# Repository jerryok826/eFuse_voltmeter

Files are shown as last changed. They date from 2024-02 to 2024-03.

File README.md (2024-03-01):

# eFuse Voltmeter
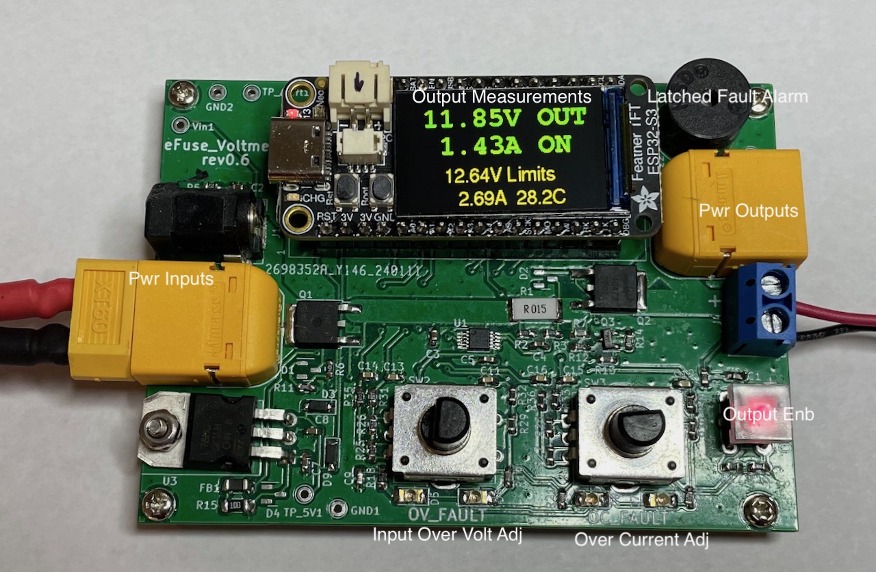
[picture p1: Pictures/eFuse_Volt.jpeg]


# eFuse Voltmeter in fault
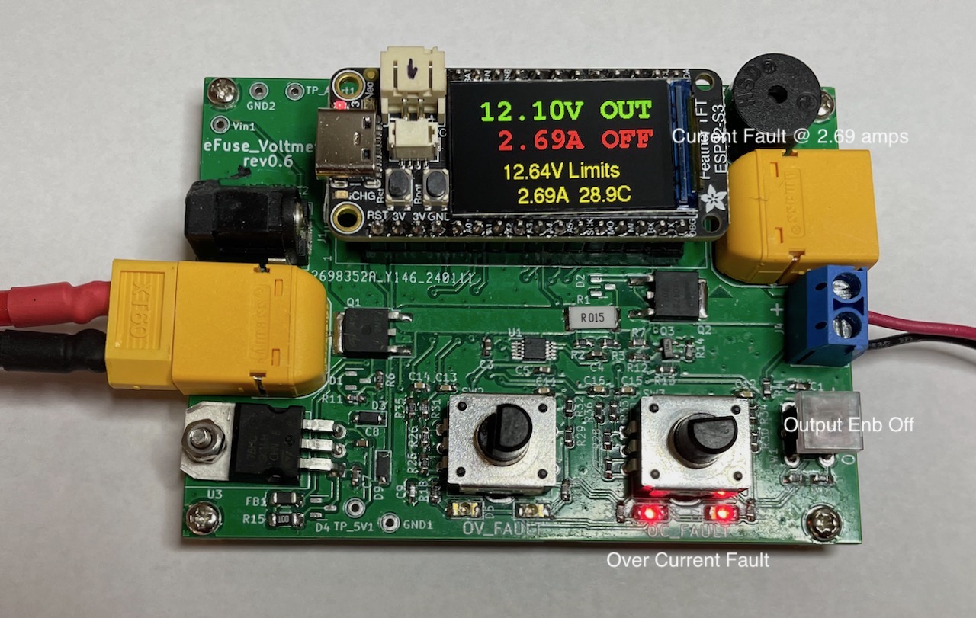
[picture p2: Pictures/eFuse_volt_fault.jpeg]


## Project Description
eFuse_Voltmeter is a protection circuit for down stream electronic devices. A eFuse. The initial reason for the device was to protect a Ham radio when adjustmenting power mosfet transistors biasing. The fets can hit thermal run-way and destroy traces.

It can be powered from any DC power source between 5 to 25 volts. Its been test up to 6 amps.  At 5 amps the two inline mostfets drop 150millvolts each and the sense resistor drops 81 millvolts. Except for the mosfets it should work at much higher currents. So two the mosfets should upgraded. 

Features:
1. Reverse power protection.
2. Adjustable input over voltage input protection
3. Adjustable over current protection.
4. Voltage and current monitoring.
5. Output power control.
6. Output power disconnected on fault.
7. Audio alarm on fault.

When an over voltage or an over current event happens the board will disable its output. The fault state is latched until the control buttons is pressed. Apond a fault an audio alarm is also actived and a fault LEDs is lite. The fault value is indicted by its red measurement value and the fault RED led is lite. A fault is cleared by pressing the adjusement button. The output button needs to be press again to reable the boards output.
 
### Project Status
The project is basically complete. Working on improvements.

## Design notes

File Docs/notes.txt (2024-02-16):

https://learn.adafruit.com/adafruit-hallowing/uf2-bootloader-details

https://github.com/adafruit/Adafruit_Learning_System_Guides/blob/main/Factory_Tests/Feather_ESP32S2_TFT_FactoryTest/Feather_ESP32S2_TFT_FactoryTest.ino

14:25:53.303 -> [0;32mI (611) esp_image: segment 0: paddr=00010020 vaddr=3c040020 size=0edf4h ( 60916) map[0m
14:25:53.303 -> [0;32mI (621) esp_image: segment 1: paddr=0001ee1c vaddr=3fc916f0 size=011fch (  4604) load[0m
14:25:53.303 -> [0;32mI (622) esp_image: segment 2: paddr=00020020 vaddr=42000020 size=33ec0h (212672) map[0m
14:25:53.336 -> [0;32mI (658) esp_image: segment 3: paddr=00053ee8 vaddr=3fc928ec size=02634h (  9780) load[0m
14:25:53.336 -> [0;32mI (661) esp_image: segment 4: paddr=00056524 vaddr=40374000 size=0d6e4h ( 55012) load[0m
14:25:53.370 -> [0;32mI (680) boot: Loaded app from partition at offset 0x10000[0m
14:25:53.370 -> [0;32mI (681) boot: Disabling RNG early entropy source...[0m
14:25:53.370 -> E (699) esp_core_dump_flash: No core dump partition found!
14:25:53.370 -> E (699) esp_core_dump_flash: No core dump partition found!

// reg at page 21
10:32:37.497 -> INA228 reg[00] 0x0000
10:32:37.497 -> INA228 reg[01] 0xFB68
10:32:37.497 -> INA228 reg[02] 0x1000
10:32:37.497 -> INA228 reg[03] 0x0000
10:32:37.497 -> INA228 reg[04] 0x00D2
10:32:37.497 -> INA228 reg[05] 0x0DCB
10:32:37.497 -> INA228 reg[06] 0x0ADE
10:32:37.530 -> INA228 reg[07] 0x00D2
10:32:37.530 -> INA228 reg[08] 0x002D
10:32:37.530 -> INA228 reg[09] 0x0000
10:32:37.530 -> INA228 reg[0A] 0x0000
10:32:37.530 -> INA228 reg[0B] 0x4003 // DIAG_ALRT pg 26
10:32:37.530 -> INA228 reg[0C] 0x7FFF
10:32:37.530 -> INA228 reg[0D] 0x8000
10:32:37.530 -> INA228 reg[0E] 0x7FFF
10:32:37.530 -> INA228 reg[0F] 0x0000
10:32:37.530 -> INA228 reg[10] 0x7FFF
10:32:37.530 -> INA228 reg[11] 0xFFFF
10:32:37.530 -> INA228 reg[3E] 0x5449
10:32:37.530 -> INA228 reg[3F] 0x2281

10:32:37.530 -> Averaging counts: 16
10:32:37.530 -> Voltage conversion time: 150 uS
10:32:37.530 -> Current conversion time: 280 uS

Address Acronym
Register NameRegister Size (bits)
Section
0hCONFIGConfiguration16Go
1hADC_CONFIGADC Configuration16Go
2hSHUNT_CALShunt Calibration16Go
3hSHUNT_TEMPCOShunt Temperature Coefficient16Go
4hVSHUNTShunt Voltage Measurement24Go
5hVBUSBus Voltage Measurement24Go
6hDIETEMPTemperature Measurement16Go
7hCURRENTCurrent Result24Go
8hPOWERPower Result24Go
9hENERGYEnergy Result40Go
AhCHARGECharge Result40Go
BhDIAG_ALRTDiagnostic Flags and Alert16Go
ChSOVLShunt Overvoltage Threshold16Go
DhSUVLShunt Undervoltage Threshold16Go
EhBOVLBus Overvoltage Threshold16Go
FhBUVLBus Undervoltage Threshold16Go
10hTEMP_LIMITTemperature Over-Limit
Threshold16Go
11hPWR_LIMITPower Over-Limit Threshold16Go
3EhMANUFACTURER_IDManufacturer ID16Go
3FhDEVICE_IDDevice ID16Go

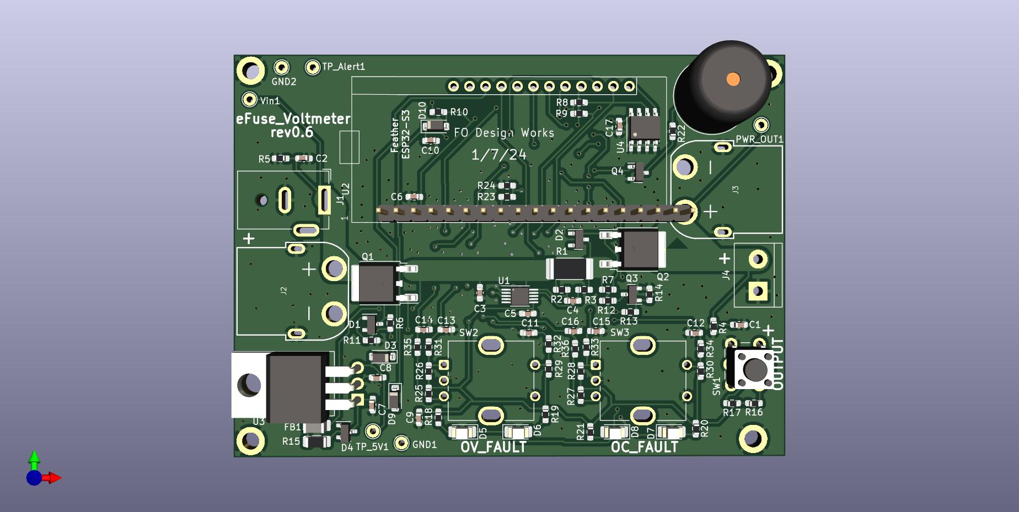
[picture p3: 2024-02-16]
Hardware/eFuse_voltmeter_r6.jpg

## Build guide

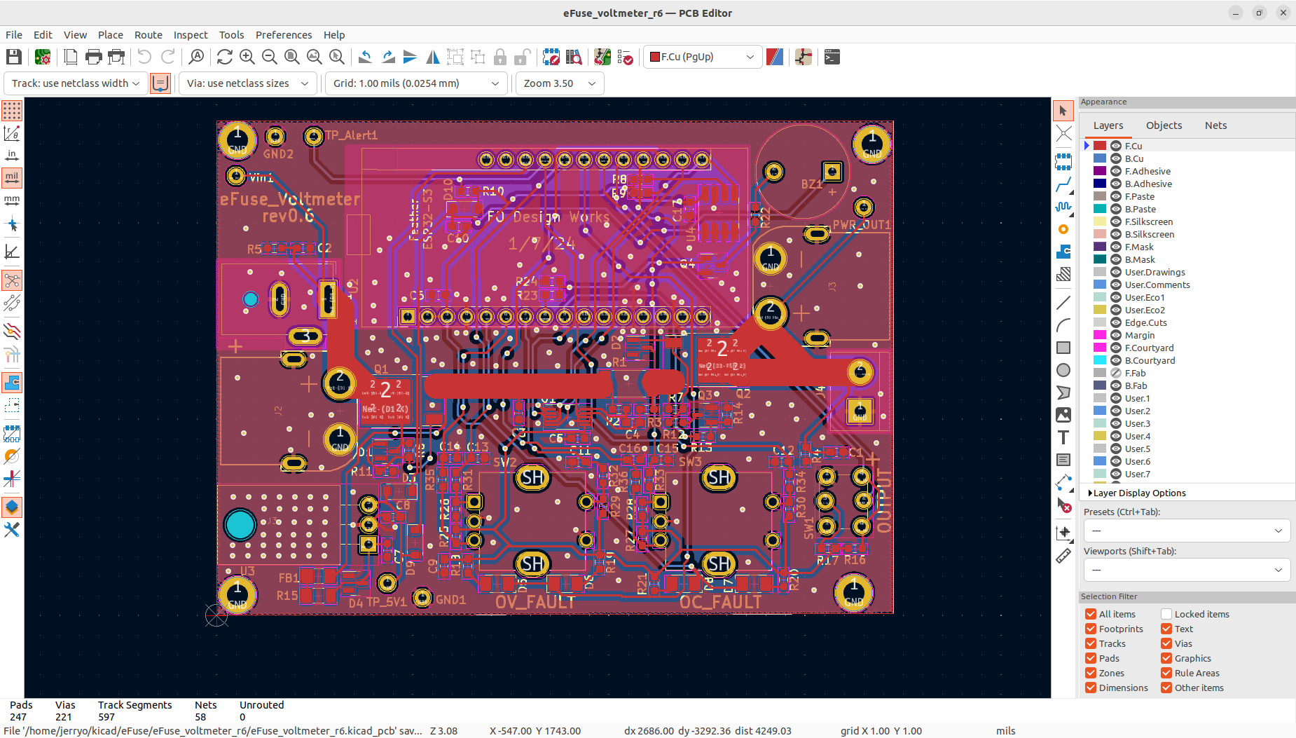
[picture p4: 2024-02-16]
Pictures/arduino_setup.png

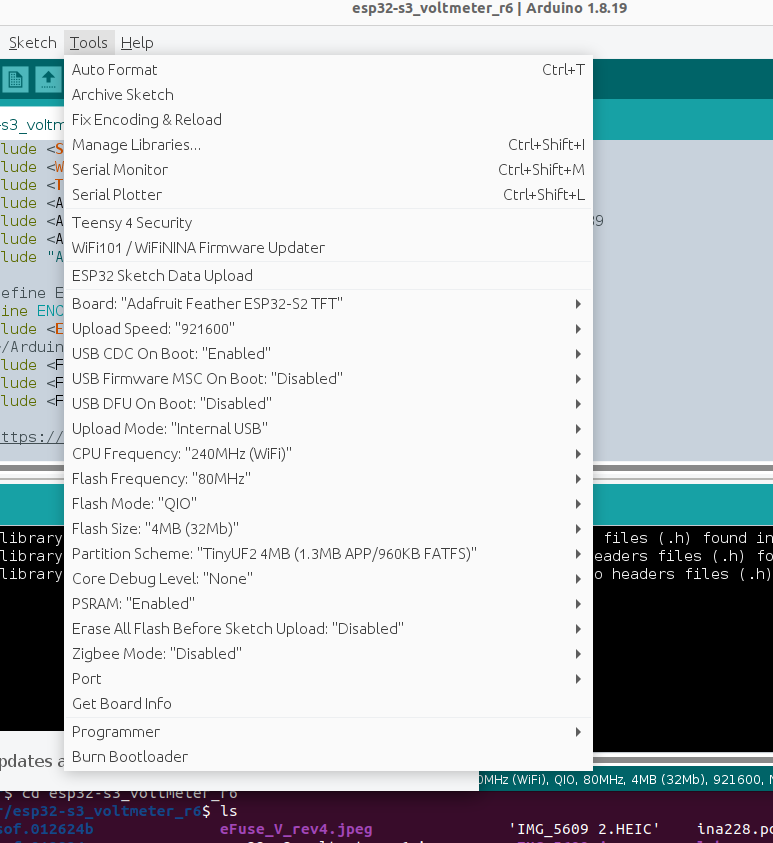
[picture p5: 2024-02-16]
Pictures/arduino_S2_setup.png

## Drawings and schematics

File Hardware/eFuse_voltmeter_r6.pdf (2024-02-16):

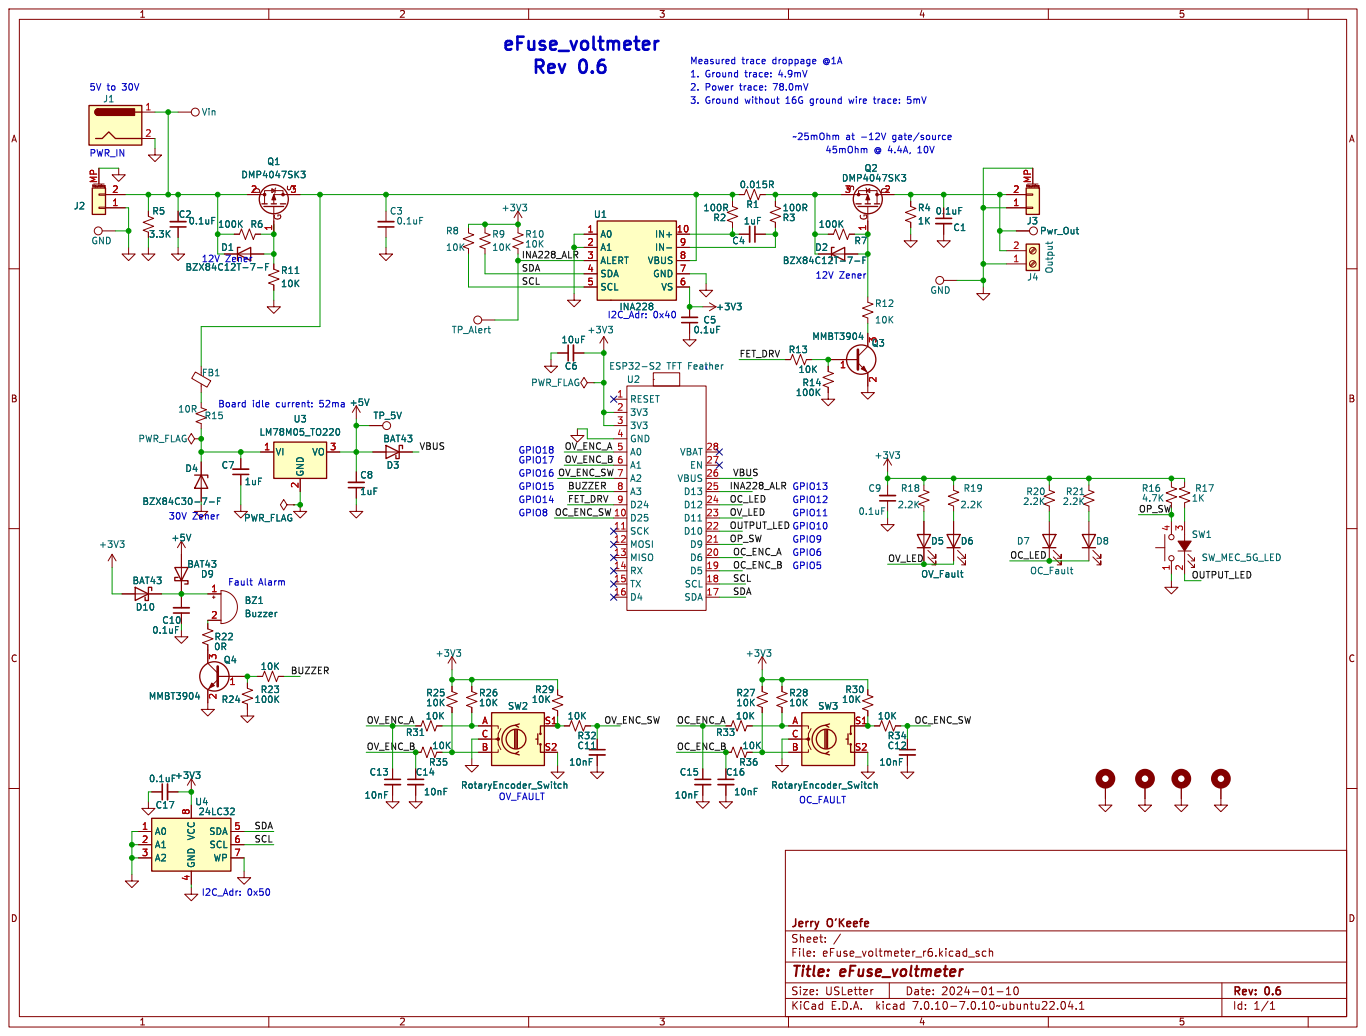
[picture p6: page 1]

4 SDA 5 SCL 6 WP 7 VCC

Id: 1/1 Title: eFuse_voltmeter File: eFuse_voltmeter_r6.kicad_sch Sheet: / Jerry O'Keefe

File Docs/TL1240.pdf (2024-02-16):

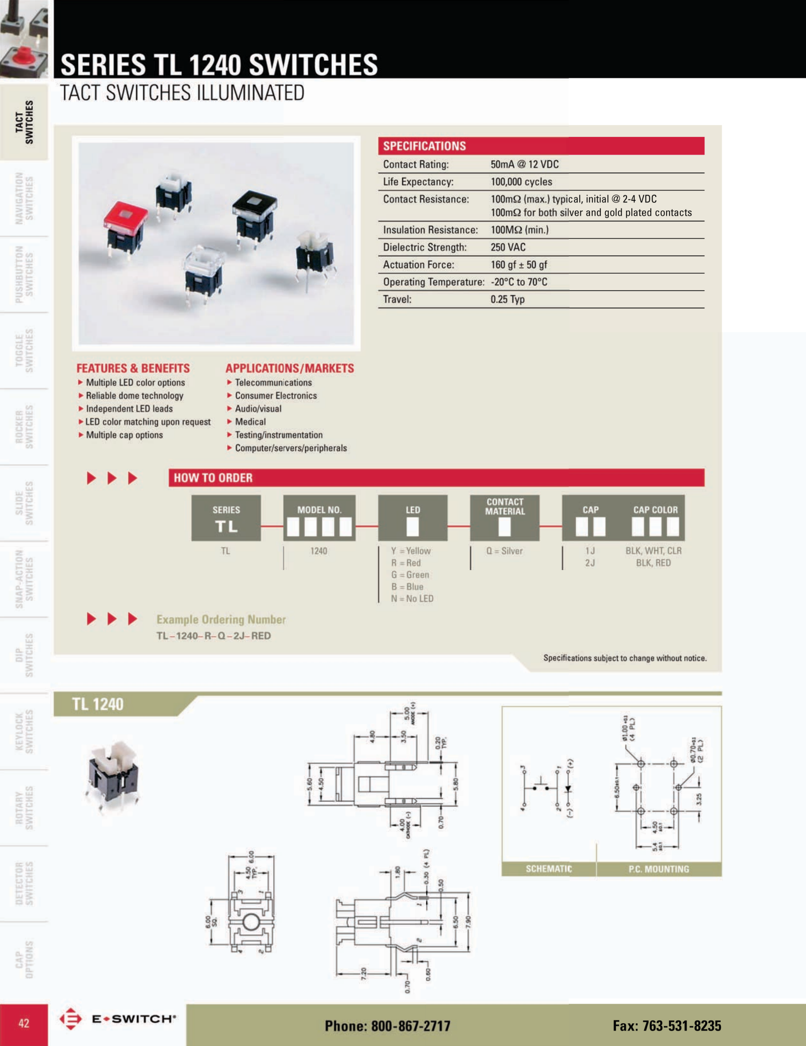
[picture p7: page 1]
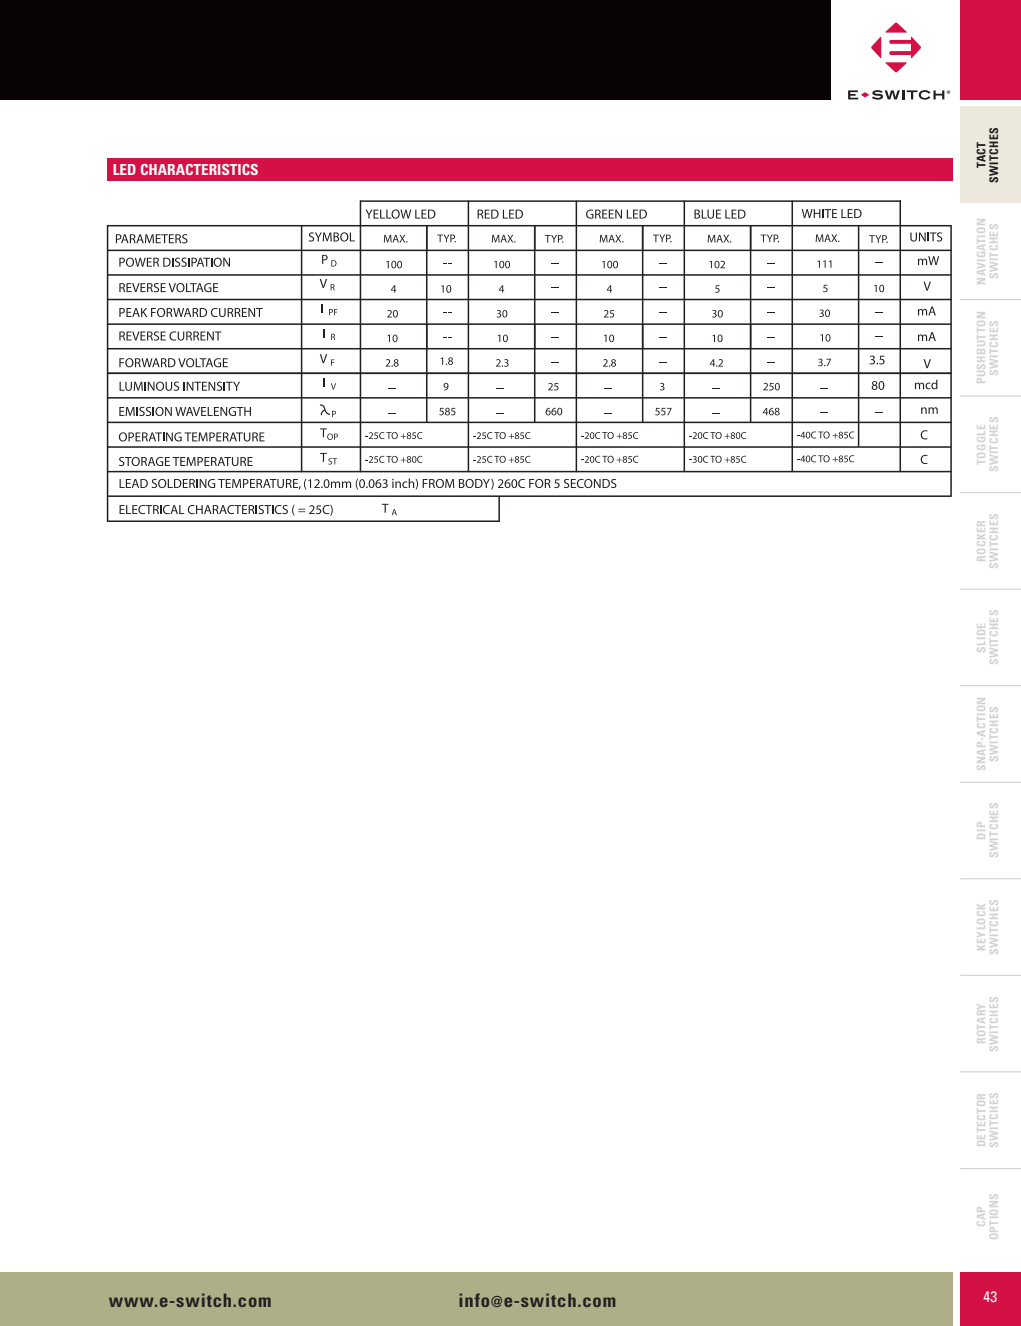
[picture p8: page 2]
www.e-switch.com; info; @e-switch.com; 43TACT SWITCHES NAVIGATION SWITCHES PUSHBUTTON SWITCHES TOGGLE SWITCHES ROCKER SWITCHES SLIDE SWITCHES SNAP⁻ACTION SWITCHES DIP SWITCHES KEYLOCK SWITCHES ROTARY SWITCHES DETECTOR SWITCHES CAP OPTIONS; LED CHARACTERISTICS

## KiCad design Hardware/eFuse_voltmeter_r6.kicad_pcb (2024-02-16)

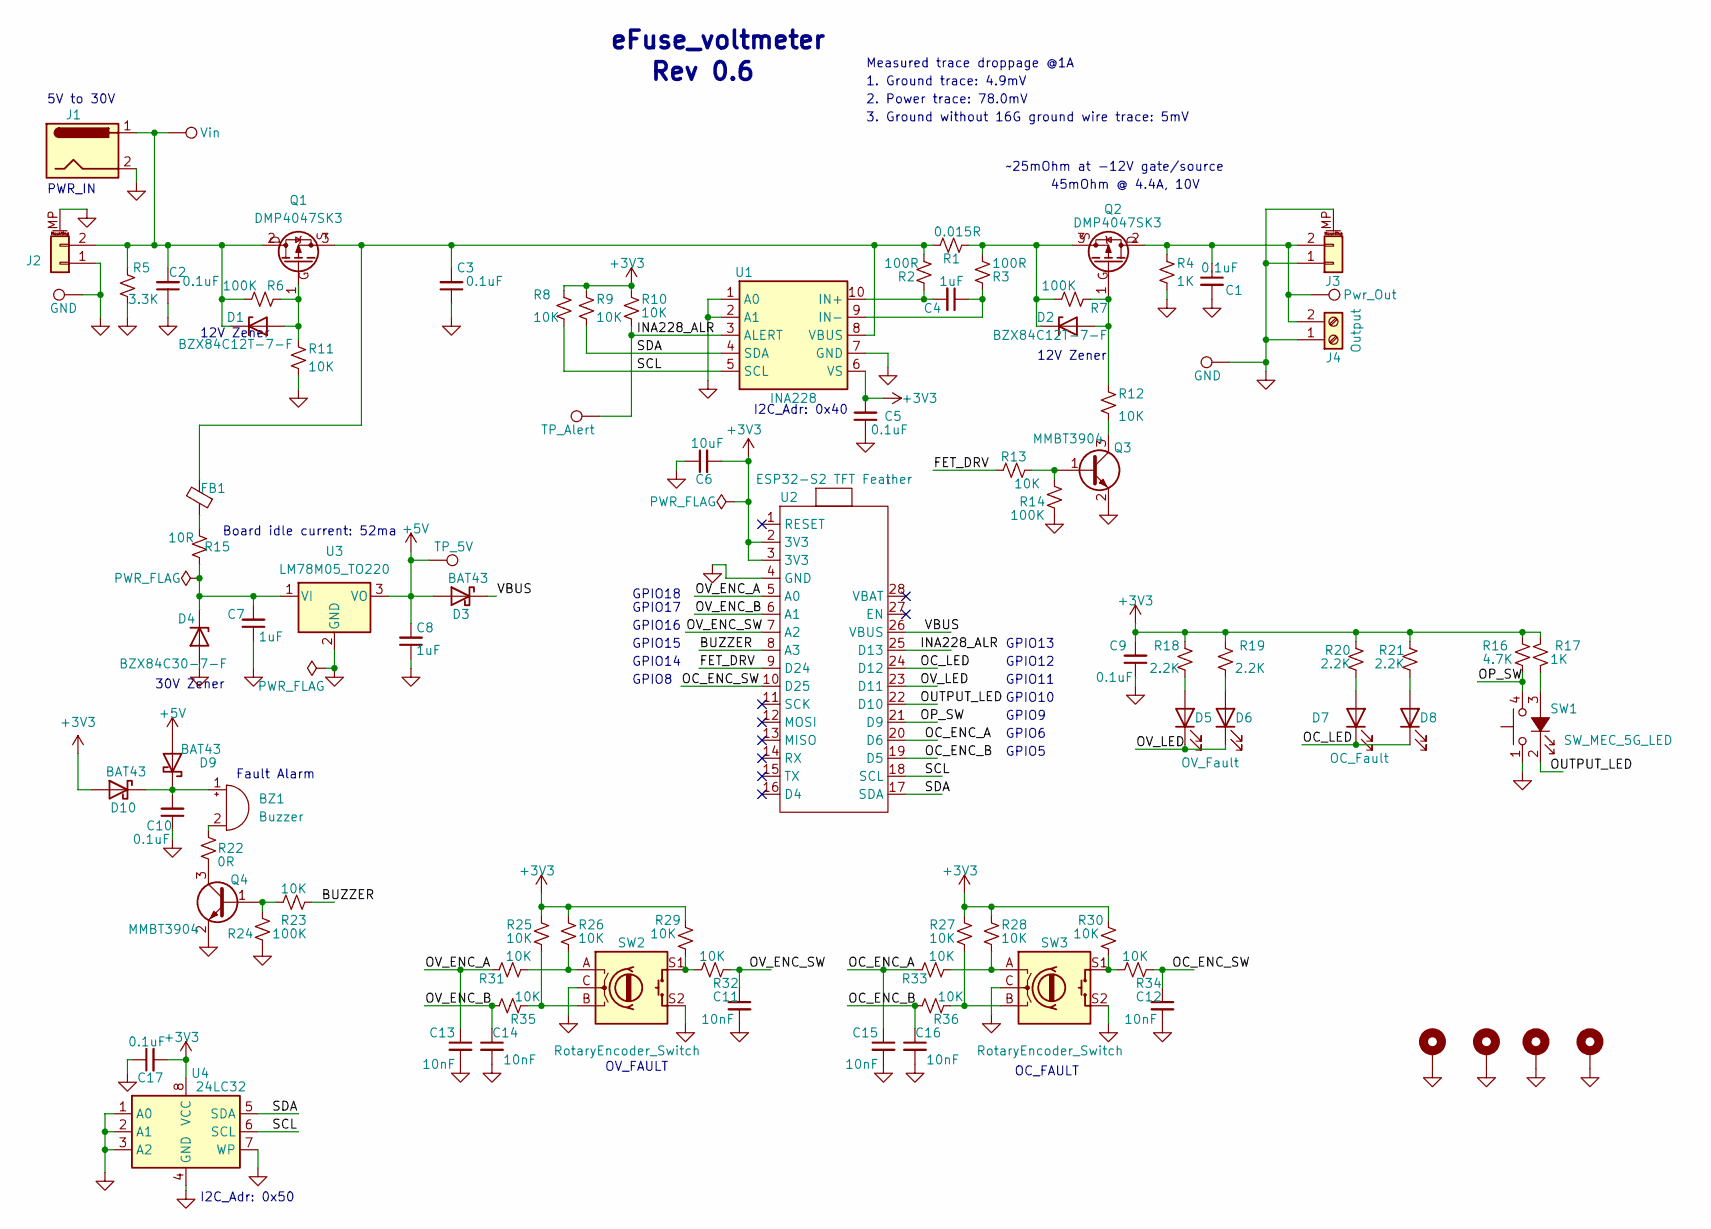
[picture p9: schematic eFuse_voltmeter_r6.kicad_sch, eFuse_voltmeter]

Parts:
BZ1: Buzzer; Buzzer_12x9.5RM7.6
C1, C2, C3, C5, C9, C10, C17: 0.1uF; C_0603_1608Metric_Pad1.08x0.95mm_HandSolder
C4, C7, C8: 1uF; C_0603_1608Metric_Pad1.08x0.95mm_HandSolder
C6: 10uF; C_0603_1608Metric_Pad1.08x0.95mm_HandSolder
C11, C12, C13, C14, C15, C16: 10nF; C_0603_1608Metric_Pad1.08x0.95mm_HandSolder
D1, D2: BZX84C12T-7-F; SOT-23
D3, D9, D10: BAT43; D_SOD-123
D4: BZX84C30-7-F; SOT-23
D5, D6: OV_Fault; LED_1206_3216Metric_Pad1.42x1.75mm_HandSolder
D7, D8: OC_Fault; LED_1206_3216Metric_Pad1.42x1.75mm_HandSolder
FB1: FerriteBead, 6A 1 9mΩ 33Ω@100MHz ±25% 1206 Ferrit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; L_1206_3216Metric_Pad1.42x1.75mm_HandSolder
GND1, GND2: GND; TestPoint_THTPad_D2.0mm_Drill1.0mm
H1, H2, H3, H4: MountingHole_Pad; MountingHole_2.7mm_M2.5_ISO14580_Pad
J1: INPUT_PWR; BarrelJack_GCT_DCJ200-10-A_Horizontal
J2, J3: Conn_01x02_MountingPin; Amass_XT60PW-M
J4: Output; TerminalBlock_bornier-2_P5.08mm
PWR_OUT1: Pwr_Out; TestPoint_THTPad_D2.0mm_Drill1.0mm
Q1, Q2: DMP4047SK3; TO-252-2
Q3, Q4: MMBT3904; SOT-23
R1: 0.015R; R_2512_6332Metric_Pad1.40x3.35mm_HandSolder; LCSC C159433
R2, R3: 100R; R_0603_1608Metric_Pad0.98x0.95mm_HandSolder
R4, R17: 1K; R_0603_1608Metric_Pad0.98x0.95mm_HandSolder
R5: 3.3K; R_0603_1608Metric_Pad0.98x0.95mm_HandSolder
R6, R7, R14, R24: 100K; R_0603_1608Metric_Pad0.98x0.95mm_HandSolder
R8, R9, R10, R11, R12, R13, R23, R25, R26, R27, R28, R29, R30, R31, R32, R33, R34, R35, R36: 10K; R_0603_1608Metric_Pad0.98x0.95mm_HandSolder
R15: 10R; R_1206_3216Metric_Pad1.30x1.75mm_HandSolder
R16: 4.7K; R_0603_1608Metric_Pad0.98x0.95mm_HandSolder
R18, R19, R20, R21: 2.2K; R_0603_1608Metric_Pad0.98x0.95mm_HandSolder
R22: 0R; R_0603_1608Metric_Pad0.98x0.95mm_HandSolder
SW1: SW_MEC_5G_LED; SW_PUSH_LED_6mm
SW2, SW3: RotaryEncoder_Switch; RotaryEncoder_Bourns_Vertical_PEC12R-3x17F-Sxxxx
TP_5V1: TP_5V; TestPoint_THTPad_D2.0mm_Drill1.0mm
TP_Alert1: TP_Alert; TestPoint_THTPad_D2.0mm_Drill1.0mm
U1: INA228; VSSOP-10_3x3mm_P0.5mm
U2: ESP32-S2 TFT Feather; Feather_RP2040
U3: LM78M05_TO220; TO-220-3_Horizontal_TabDown
U4: 24LC32; SOIC-8_3.9x4.9mm_P1.27mm
Vin1: Vin; TestPoint_THTPad_D2.0mm_Drill1.0mm

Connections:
+3V3: C5.2, C6.2, C9.2, C17.2, D10.2 (A), R8.1, R9.1, R10.1, R16.2, R17.2, R18.2, R19.2, R20.2, R21.2, R25.1, R26.1, R27.1, R28.1, R29.1, R30.1, U1.6 (VS), U2.2 (3V3), U2.3 (3V3), U4.8 (VCC)
+5V: C8.2, D3.2 (A), D9.2 (A), TP_5V1.1, U3.3 (VO)
/BUZZER: R23.2, U2.8 (A3)
/FET_DRV: R13.1, U2.9 (D24)
/INA228_ALR: R10.2, TP_Alert1.1, U1.3 (ALERT), U2.25 (D13)
/OC_ENC_A: C15.1, R33.1, U2.20 (D6)
/OC_ENC_B: C16.1, R36.1, U2.19 (D5)
/OC_ENC_SW: C12.1, R34.2, U2.10 (D25)
/OC_LED: D7.1 (K), D8.1 (K), U2.24 (D12)
/OP_SW: R16.1, SW1.4 (A), U2.21 (D9)
/OUTPUT_LED: SW1.2, U2.22 (D10)
/OV_ENC_A: C13.1, R31.1, U2.5 (A0)
/OV_ENC_B: C14.1, R35.1, U2.6 (A1)
/OV_ENC_SW: C11.1, R32.2, U2.7 (A2)
/OV_LED: D5.1 (K), D6.1 (K), U2.23 (D11)
/SCL: R8.2, U1.5 (SCL), U2.18 (SCL), U4.6 (SCL)
/SDA: R9.2, U1.4 (SDA), U2.17 (SDA), U4.5 (SDA)
/VBUS: D3.1 (K), U2.26 (VBUS)
GND: C1.2, C2.1, C3.1, C5.1, C6.1, C7.1, C8.1, C9.1, C10.1, C11.2, C12.2, C13.2, C14.2, C15.2, C16.2, C17.1, D4.1 (A), GND1.1, GND2.1, H1.1, H2.1, H3.1, H4.1, J1.2, J2.1, J2.MP (MountPin), J3.1, J3.MP (MountPin), J4.1, Q3.2 (E), Q4.2 (E), R4.2, R5.2, R11.2, R14.2, R24.2, SW1.1, SW2.C, SW2.S2, SW3.C, SW3.S2, U1.1 (A0), U1.2 (A1), U1.7 (GND), U2.4 (GND), U3.2 (GND), U4.1 (A0), U4.2 (A1), U4.3 (A2), U4.4 (GND), U4.7 (WP)
unnamed: BZ1.2 (+), R22.2
unnamed: BZ1.1 (-), C10.2, D9.1 (K), D10.1 (K)
unnamed: D1.1 (A), Q1.1 (G), R6.2, R11.1
unnamed: C2.2, D1.3 (K), J1.1, J2.2, Q1.2 (D), R5.1, R6.1, Vin1.1
unnamed: D2.1 (A), Q2.1 (G), R7.2, R12.1
unnamed: D2.3 (K), Q2.3 (S), R1.1, R3.1, R7.1
unnamed: C7.2, D4.3 (K), R15.1, U3.1 (VI)
unnamed: D5.2 (A), R18.1
unnamed: D6.2 (A), R19.1
unnamed: D7.2 (A), R20.1
unnamed: D8.2 (A), R21.1
unnamed: FB1.1, R15.2
unnamed: C1.1, J3.2, J4.2, PWR_OUT1.1, Q2.2 (D), R4.1
unnamed: C3.2, FB1.2, Q1.3 (S), R1.2, R2.1, U1.8 (VBUS)
unnamed: Q3.1 (B), R13.2, R14.1
unnamed: Q3.3 (C), R12.2
unnamed: Q4.1 (B), R23.1, R24.1
unnamed: Q4.3 (C), R22.1
unnamed: R25.2, R35.2, SW2.B
unnamed: R26.2, R31.2, SW2.A
unnamed: R27.2, R36.2, SW3.B
unnamed: R28.2, R33.2, SW3.A
unnamed: R29.2, R32.1, SW2.S1
unnamed: R30.2, R34.1, SW3.S1
unnamed: R17.1, SW1.3 (K)
unnamed: C4.2, R2.2, U1.10 (IN+)
unnamed: C4.1, R3.2, U1.9 (IN-)

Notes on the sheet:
Board idle current: 52ma
1. Ground trace: 4.9mV
I2C_Adr: 0x40
GPIO16
GPIO9
2. Power trace: 78.0mV
GPIO14
GPIO13
GPIO10
GPIO15
GPIO6
~25mOhm at -12V gate/source
PWR_IN
eFuse_voltmeter
GPIO11
Rev 0.6
GPIO17
Measured trace droppage @1A
5V to 30V
GPIO8
45mOhm @ 4.4A, 10V
12V Zener
OV_FAULT
GPIO12
Fault Alarm
I2C_Adr: 0x50
GPIO5
3. Ground without 16G ground wire trace: 5mV
GPIO18
30V Zener
OC_FAULT

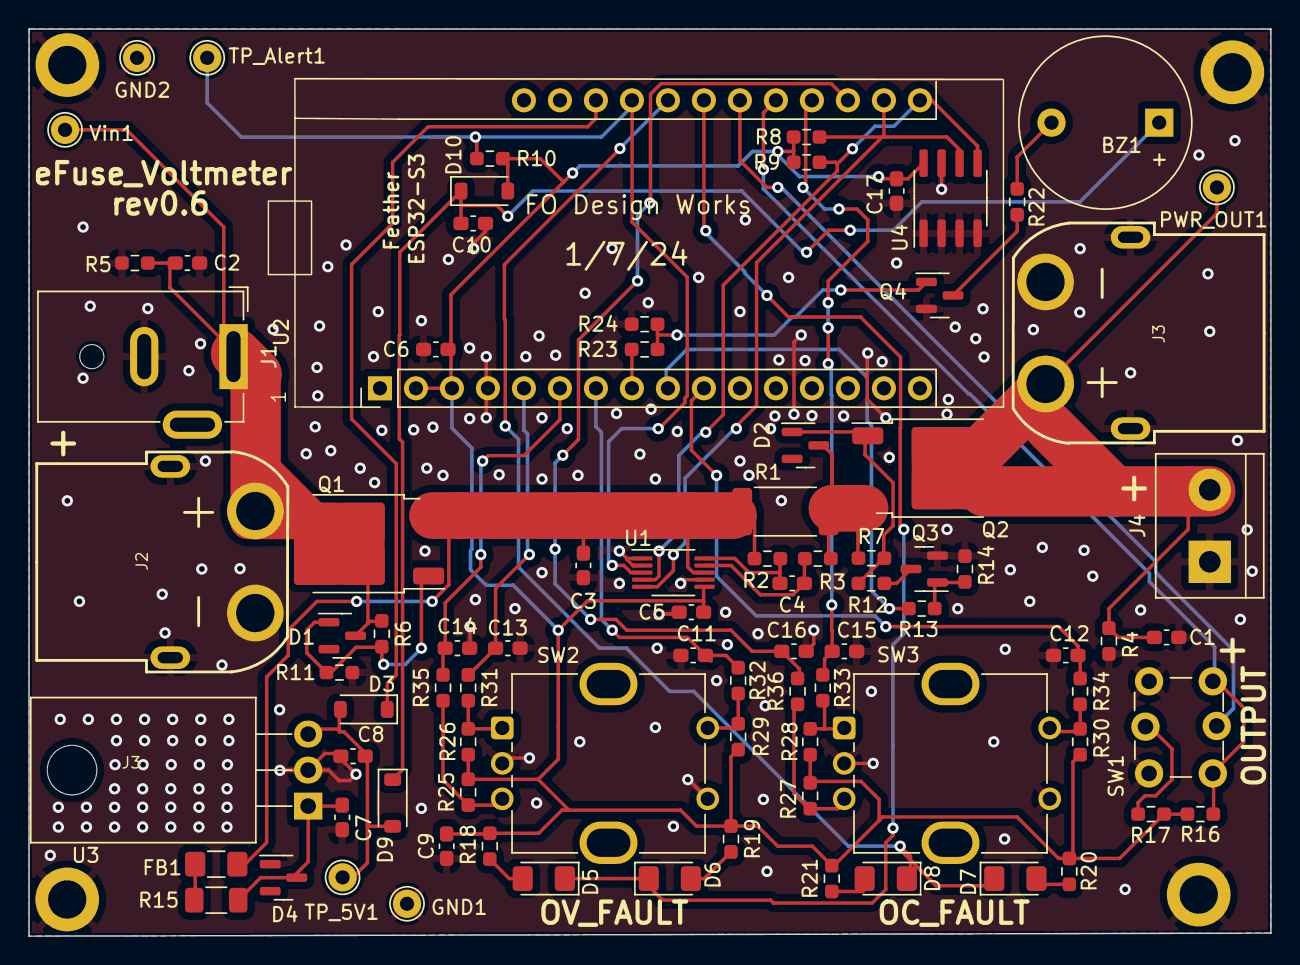
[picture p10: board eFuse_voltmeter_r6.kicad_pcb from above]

Board: 2 copper layers, 87.6 x 64.0 mm, 90 parts (0 on the bottom side), 46 nets.

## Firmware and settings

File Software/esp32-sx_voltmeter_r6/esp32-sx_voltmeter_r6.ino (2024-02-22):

#include <SPI.h>
#include <Wire.h>
#include <Toggle.h>
#include <Adafruit_GFX.h>
#include <Adafruit_ST7789.h>    // Hardware-specific library for ST7789
#include "Adafruit_INA228.h"

#define ESP32 ///
//#define ENCODER_DO_NOT_USE_INTERRUPTS
#define ENCODER_USE_INTERRUPTS
#include <Encoder.h>  // https://github.com/PaulStoffregen/Encoder/
// ~/Arduino/libraries/Adafruit-GFX-Library/Fonts/
#include <Fonts/FreeSans12pt7b.h>
#include <Fonts/FreeMono18pt7b.h>
#include <Fonts/FreeMonoBold18pt7b.h>

// https://github.com/adafruit/Adafruit_INA228

// indent -gnu -br -cli2 -lp -nut -l100 esp32-s3_voltmeter_r4.ino

Adafruit_ST7789 display = Adafruit_ST7789 (TFT_CS, TFT_DC, TFT_RST);
GFXcanvas16 canvas (240, 135);

int fram_get_dev_id (void);
void i2c_scan (void);
int fram_read_bytes (uint16_t fram_adr, uint8_t * ptr, int len);
int fram_write_bytes (uint16_t fram_adr, uint8_t * ptr, int len);
int ina228_reg_read (int reg);
int ina228_reg_write(int reg, uint16_t reg_value);

Adafruit_INA228 ina228 = Adafruit_INA228 ();

const float sense_resistor = 0.015;
const float fet_on_resistance = 0.025;

// GPIO outputs
const int OC_led = 12;          // 7;       // GPIO7
const int OV_led = 11;          //8;        // GPIO
const int OUTPUT_led = 10;      // 10;      // GPIO
const int BUZZER = 15;          // 6;       // GPIO
const int FETDRV = 14;          // GPIO
const int INA228_ALR = 13;      // GPIO13  INA228_ALR

// GPIO inputs
const int OP_SW = 9;            // 18;       // GPIO18 ??
const int OV_ENC_SW = 16;       //12; // 25; // GPIO25 ??
const int OC_ENC_SW = 8;        //12; // 25; // GPIO25 ??

const int OV_ENC_A = 18; 
const int OV_ENC_B = 17;  
const int OC_ENC_A = 6; 
const int OC_ENC_B = 5; 

int ina228_alr_int_flag=0; // int flag

static int output_state = 0;
static int fault_state = 0;
static float voltage_limit = 0.0;
static float current_limit = 0.0;
static float oc_pot_setting, ov_pot_setting;
static int ov_fault = 0;
static int oc_fault = 0;

static float max_voltage_limit = 20.0;
static float max_current_limit = 10.0;  // normal value of 4A
static float fault_voltage = 0.0;
static float fault_current = 0.0;

long Position_Diff = 0.0;
static int dirty_ov_setting = 0;
static int dirty_oc_setting = 0;

#define DEFAULT_OV_LIMIT  (13.5)
#define DEFAULT_OC_LIMIT  (2.0)

// Change these two numbers to the pins connected to your encoder.
//   Best Performance: both pins have interrupt capability
//   Good Performance: only the first pin has interrupt capability
//   Low Performance:  neither pin has interrupt capability
//   avoid using pins with LEDs attached

Encoder OC_Enc(OC_ENC_A,OC_ENC_B); // 5,6); // 5, 6);
Encoder OV_Enc(OV_ENC_B,OV_ENC_A); // 17,18); // 5, 6);

static signed long old_OV_Position = 0;
static signed long new_OV_Position = 0;

static long old_OC_Position = 0;
static long new_OC_Position = 0;

#define OV_FAULT_BIT  (0x1 << 4)
#define OC_FAULT_BIT  (0x1 << 6)

void led_test (int state);
void alert_bell (int state);
void fet_drv_state (int state);
void output_led_set (int state);
void ov_led_set (int state);
void oc_led_set (int state);
void buzzer_set (int state);

Toggle button (OP_SW);

void
reg_dump (int reg)
{
  int reg_value = 0x73;

  reg_value = ina228_reg_read (reg); 
//  reg_value = ina228.reg_read (reg);  
  Serial.printf ("INA228 reg[%02X] 0x%04X\n", reg, reg_value);
}

void
output_led_set (int state)
{
  pinMode (OUTPUT_led, OUTPUT);
  if (state == 0) {
    digitalWrite (OUTPUT_led, HIGH);  // LED off
  }
  else {
    digitalWrite (OUTPUT_led, LOW); // LED on
  }
}

void
ov_led_set (int state)
{
  pinMode (OV_led, OUTPUT);
  if (state == 0) {
    digitalWrite (OV_led, HIGH);  // LED off
    ov_fault = 0;
  }
  else {
    digitalWrite (OV_led, LOW); // LED on
    ov_fault = 1;
  }
}

void
oc_led_set (int state)
{
  pinMode (OC_led, OUTPUT);
  if (state == 0) {
    digitalWrite (OC_led, HIGH); // LED off
    oc_fault = 0;
  }
  else {
    digitalWrite (OC_led, LOW); // LED on
    oc_fault = 1;
  }
}

void
buzzer_set (int state)
{
  pinMode (BUZZER, OUTPUT);
  if (state == 0) {
    digitalWrite (BUZZER, LOW); // off
  }
  else {
    digitalWrite (BUZZER, HIGH); // on
  }
}

void
voltage_limit_set (float voltage)
{
  int reg_value = 0;

  // set voltage limit
  reg_value = (int) (voltage / 0.003125);
//  ina228.reg_write (0x0e, reg_value);
  ina228_reg_write(0x0e, reg_value);

  Serial.printf ("%s(%d) V Limit set: %03.3fV, reg[%d]: 0x%04X\n", __func__,__LINE__,voltage, 0x0e, reg_value);

  // set enable V fault
  reg_value = ina228_reg_read (0x0B); 
//  reg_value = ina228.reg_read (0x0B);   // jok
  reg_value &= (1 << 6); // Clear all but OC flag
  reg_value |= 1 << 4;          // bus over voltage
  reg_value |= 1 << 15;         // Set Alert latch bit
//  ina228.reg_write (0x0b, reg_value);
  ina228_reg_write(0x0b, reg_value);

  Serial.printf ("%s(%d) over V alert enabled: %03.3fV, reg[%d]: 0x%04X\n", __func__,__LINE__,voltage, 0x0B, reg_value);
}

void
current_limit_set (float current)
{
  int reg_value = 0;
  float shunt_voltage;

  // set current limit
  shunt_voltage = current * sense_resistor;
//  ina228.reg_write (0x0c, (float) (shunt_voltage / 0.000005));
  ina228_reg_write (0x0c, (float) (shunt_voltage / 0.000005));
  Serial.printf ("%s(%d) I Limit set: %03.3fV, reg[%d]: 0x%04X\n", __func__,__LINE__,current, 0x0c, reg_value);

  // set enable V fault
  reg_value = ina228_reg_read (0x0B); 
//  reg_value = ina228.reg_read (0x0B);   // jok
  reg_value &= (1 << 4); // Clear all but OV flag
  reg_value |= 1 << 6;          // bus over current
  reg_value |= 1 << 15;         // Set Alert latch bit
//  ina228.reg_write (0x0B, reg_value);
  ina228_reg_write(0x0b, reg_value);

  Serial.printf ("%s(%d) I Limit set: %03.3fA, reg[%d]: 0x%04X\n", __func__,__LINE__, current, 0x0c, reg_value);
}

void
output_pin_test (int pin_to_test)
{
  int toggle_bit = 0;
  pinMode (pin_to_test, OUTPUT);

  while (1) {
    if (toggle_bit) {
      digitalWrite (pin_to_test, HIGH);
      toggle_bit = !toggle_bit;
      delay (1);
    }
    else {
      digitalWrite (pin_to_test, LOW);
      toggle_bit = !toggle_bit;
      delay (1);
    }
  }
}

// switch test,  AL_RST_SW
//    alarm_reset_sw_state(void)
void
sw_test (int pin_nub)           // AL_RST_SW
{
  pinMode (pin_nub, INPUT_PULLUP);
  while (1) {
    if (digitalRead (pin_nub) == 0) {
      oc_led_set (0);
      ov_led_set (1);
    }
    else {
      oc_led_set (1);
      ov_led_set (0);
    }
    delay (10);
  }
}

void
alert_bell (int state)
{
  if (state) {
    buzzer_set (1);
  }
  else {
    buzzer_set (0);
  }
}

void
fet_drv_state (int state)
{
  pinMode (FETDRV, OUTPUT);
  if (state) {
    output_state = 1;
    output_led_set (1);
    digitalWrite (FETDRV, HIGH); // on
  }
  else {
    output_state = 0;
    output_led_set (0);
    digitalWrite (FETDRV, LOW); // off
  }
}

void
led_test (int state)
{
  if (state) { // on
    output_led_set (1); 
    oc_led_set (1);
    ov_led_set (1);
  }
  else {
    output_led_set (0); 
    oc_led_set (0);
    ov_led_set (0);
  }
}

void
read_voltage_current (float *voltage, float *current)
{
  float fet_sense_r_V_drop = 0.0;

  *voltage = ina228.readBusVoltage () / 1000.0;
  *current = ina228.readCurrent () / 1000.0;    // sensor current reading.
  *current -= *voltage / 1000;  // adjust out 1K load resistor current.

  fet_sense_r_V_drop = (*current) * (sense_resistor + fet_on_resistance); // ~0.035 ohms
  *voltage -= fet_sense_r_V_drop;
}

// return true if reset sw pressed
int
alarm_reset_sw_state (void)
{
  if ((digitalRead (OV_ENC_SW) == 0) || (digitalRead (OC_ENC_SW) == 0)) { 
    return 1;
  }
  else {
    return 0;
  }
}

void
display_limits (void)
{
  canvas.fillScreen (ST77XX_BLACK);     // SH110X_BLACK);
  canvas.setFont (&FreeSans12pt7b);     // FreeMono18pt7b
  canvas.setCursor (0, 0);
  canvas.setTextColor (ST77XX_WHITE);   // ST77XX_RED ST77XX_YELLOW ST77XX_GREEN ST77XX_BLUE ST77XX_WHITE
  canvas.printf ("\n           V&C Limits\n");
  canvas.setTextColor (ST77XX_GREEN);
  canvas.printf (" %19.2fV\n", voltage_limit);
  canvas.setTextColor (ST77XX_YELLOW);
  canvas.printf (" %19.2fA\n", current_limit);
  display.drawRGBBitmap (0, 0, canvas.getBuffer (), 240, 135);
}

void
display_readings (void)
{
  float voltage = 0.0;
  float current = 0.0;
  float temperature = 0.0;
  static float last_current = 0.0;

  read_voltage_current (&voltage, &current);
  if (fault_state) {
//    voltage = fault_voltage;  // I don't think this is needed
    current = fault_current;    // Show fault current value before output this abled.
  }
  temperature = ina228.readDieTemp ();

  canvas.setFont (&FreeMonoBold18pt7b); // FreeSans12pt7b); // FreeMono18pt7b
  canvas.fillScreen (ST77XX_BLACK);     // SH110X_BLACK);
  canvas.setCursor (0, 0);
  canvas.setTextColor (ST77XX_GREEN);
  if (ov_fault) {
    canvas.setTextColor (ST77XX_RED);
  }
  // screen is 4 rows by 18 chars
  canvas.printf ("\n%6.2fV OUT\n", voltage);
  // show current
  if (current < 0.0) {
    current = 0.0;
  }
  canvas.setTextColor (ST77XX_GREEN);
  if (oc_fault) {
    canvas.setTextColor (ST77XX_RED);
  }
  if (output_state) {
    canvas.printf ("%6.2fA ON\n", current);
  } else {
    canvas.printf ("%6.2fA OFF\n", current);
  }
  canvas.setTextColor (ST77XX_GREEN);

  canvas.setTextColor (ST77XX_YELLOW); // output_state = 1;
  canvas.setFont (&FreeSans12pt7b);
  canvas.printf (" %12.2fV Limits\n", voltage_limit);
  canvas.printf (" %14.2fA  %02.1fC\n", current_limit,temperature );

//  canvas.printf ("012345678901234567\n");
  display.drawRGBBitmap (0, 0, canvas.getBuffer (), 240, 135);
}

void
display_update (void)
{
  float voltage = 0.0;
  float current = 0.0;
  float temperature = 0.0;
  static float last_current = 0.0;

  read_voltage_current (&voltage, &current);
  temperature = ina228.readDieTemp ();

  if (alarm_reset_sw_state ()) {        // check reset button
    display_limits ();
  }
  else {
    display_readings ();
  }
//  Serial.printf(" %3.3fV,  %3.3fA, %3.1f C\n",voltage,current,temperature);
}

// #define DEFAULT_OV_LIMIT  (13.5)
// #define DEFAULT_OC_LIMIT  (2.0)
float getVoltageSetting()
{
  unsigned long start_time = micros();
  uint32_t voltage=0;
  float voltage_limit;

  fram_read_bytes (0, (uint8_t *)&voltage, sizeof(voltage));
  voltage_limit = ((float)voltage) /  1000.0;
  if (voltage_limit > DEFAULT_OV_LIMIT) {
      Serial.printf("%s(%d) Out of range Voltage limit from FRAM: %3.3f, %ld us\n", __func__,__LINE__,voltage_limit, micros() - start_time);
      voltage_limit = DEFAULT_OV_LIMIT;
      saveVoltageSetting(voltage_limit);
  } 
  Serial.printf("%s(%d) Voltage limit from FRAM: %3.3f, %ld us\n", __func__,__LINE__,voltage_limit, micros() - start_time);
  return voltage_limit;
}

void saveVoltageSetting(float voltage_limit)
{
//  unsigned long start_time = micros();
  uint32_t voltage=0;

  voltage = voltage_limit * 1000.0;
  fram_write_bytes (0, (uint8_t *)&voltage, sizeof(voltage));

//  Serial.printf("%s(%d) Voltage_limit set value: %3.3f, %ld us\n", __func__,__LINE__,voltage_limit, micros() - start_time);
}

float getCurrentSetting()
{
//  unsigned long start_time = micros();
  uint32_t current;
  float current_limit;

  fram_read_bytes (4, (uint8_t *)&current, sizeof(current));
  current_limit = ((float)current) /  1000.0;

//  Serial.printf("%s(%d) current_limit get value: %3.3f, %ld us\n", __func__,__LINE__,current_limit, micros() - start_time);
  return current_limit;
}

void saveCurrentSetting(float current_limit)
{
//  unsigned long start_time = micros();
  uint32_t current=0;

  current = current_limit * 1000.0;
  fram_write_bytes (4, (uint8_t *)&current, sizeof(current));

//  Serial.printf("%s(%d) current_limit set value: %3.3f, %ld us\n", __func__,__LINE__,current_limit, micros() - start_time);
}

int isr_cntr=0;

void IRAM_ATTR isr() {
//    ina228_reg_read (0x0B); // read alert reg to clearit
    ina228_alr_int_flag=1;
    isr_cntr++;
}

void
setup ()
{
  Serial.begin (115200);

  output_led_set (0); 
  ov_led_set (0); 
  oc_led_set (0); 
  buzzer_set (0);
  fet_drv_state (0);

  delay(1000);
  Serial.printf("=====================================================\n");
  Serial.printf("=====================================================\n");
  Serial.printf("eFuse_voltmeter Init, Built: %s %s\n",__DATE__,__TIME__);

  // Dont know way this is required, Without it OV enc does not work. GPIO18
  //pinMode (OV_ENC_A, INPUT);  

  button.begin (OP_SW);
  button.setToggleState (0);    // set initial state 0 or 1
  button.setToggleTrigger (0);  // set trigger onPress: 0, or onRelease: 1

  // turn backlite on later
  pinMode (TFT_BACKLITE, OUTPUT);
  digitalWrite (TFT_BACKLITE, LOW); // Keep backlight off for now

  // turn on the TFT / I2C power supply
  pinMode (TFT_I2C_POWER, OUTPUT);
  digitalWrite (TFT_I2C_POWER, HIGH);

  pinMode (OP_SW, INPUT_PULLUP);
  pinMode (OV_ENC_SW, INPUT_PULLUP); // AL_RST_SW, INPUT);
  pinMode (OC_ENC_SW, INPUT_PULLUP); // AL_RST_SW, INPUT);

  // Set encoder inputs
#if 0
//  pinMode (OV_ENC_B, INPUT_PULLUP); // Does not cause ENC problems if commented out
  pinMode (OV_ENC_A, INPUT); //18, INPUT); // Voltage ENC, Not sure if or why we need this

//  pinMode (OC_ENC_B, INPUT_PULLUP); // Does not cause ENC problems if commented out
//  pinMode (OC_ENC_A, INPUT_PULLUP); // Does not cause ENC problems if commented out
#endif
  
//  i2c_scan (); // debug routines
//  fram_get_dev_id ();

  // Turn LEED and Buzzer on to sound reboot
  oc_led_set (1); // Turn on fault Leds, boot up test
  ov_led_set (1); 
  output_led_set (1); 
  buzzer_set (0); // Keep buzzer off

// If fault switch is press during boot, than preset fault limts
  if (alarm_reset_sw_state ()) {
      saveVoltageSetting(DEFAULT_OV_LIMIT);
      saveCurrentSetting(DEFAULT_OC_LIMIT);
      Serial.printf("Fault SW pressed, Used preset V & I limits.\n");
  }
  Serial.println ("Init I2C Chips");

#if 0
  Serial.println("Basic Encoder Test:");
  while(1) {
    // over voltage encoder test
    new_OV_Position = OV_Enc.read();
    if (new_OV_Position != old_OV_Position) {
       old_OV_Position = new_OV_Position;
       Serial.printf("OV_Enc: %d\n",new_OV_Position);
    }

    // over current encoder test
    new_OC_Position = OC_Enc.read();
    if (new_OC_Position != old_OC_Position) {
       old_OC_Position = new_OC_Position;
       Serial.printf("OC_Enc: %d\n",new_OC_Position);
    }
  }
#endif

  // Dump some INA228 ID regs, for debug
  ina228_reg_read (0x01);  // ADC config reg, 0xFB668
  ina228_reg_read (0x3E);  // manufacturing ID reg, 0x5449
  ina228_reg_read (0x3F);  // Devive ID reg, 0x2281

  if (!ina228.begin ()) {
    Serial.println ("Couldn't find INA228 chip");
  } else {
    Serial.println ("Found INA228 chip");
  }

  // INA228 board config
  ina228.setShunt (sense_resistor, 10.0);       // updated to match MY board
  ina228.setAveragingCount (INA228_COUNT_16);
  uint16_t counts[] = { 1, 4, 16, 64, 128, 256, 512, 1024 };
  //Serial.print ("Averaging counts: ");
  //Serial.println (counts[ina228.getAveragingCount ()]);

  // set the time over which to measure the current and bus voltage
  ina228.setVoltageConversionTime (INA228_TIME_150_us);
  ina228.setCurrentConversionTime (INA228_TIME_280_us);

  // default polarity for the alert is low on ready, but
  // it can be inverted!
  ina228.setAlertPolarity (INA228_ALERT_POLARITY_INVERTED); // Active low open-collector

  display.init (135, 240);      // Init ST7789 240x135
  display.setRotation (3);
  canvas.setFont (&FreeSans12pt7b);
  canvas.setTextColor (ST77XX_WHITE);
  canvas.fillScreen (ST77XX_BLACK);
  canvas.setCursor (0, 0); // was 0,25
//    canvas.setTextSize (0);      // 2);
//  canvas.setFont (&FreeSans12pt7b);
  canvas.setFont (&FreeMonoBold18pt7b); // FreeSans12pt7b); // FreeMono18pt7b

  canvas.setTextColor (ST77XX_WHITE);
  canvas.printf ("\n   eFuse\n");
  canvas.printf (" Voltmeter");
  display.drawRGBBitmap (0, 0, canvas.getBuffer (), 240, 135);
  digitalWrite (TFT_BACKLITE, HIGH);    // turn backlight on
  Serial.printf("Display Init done\n");

  delay (1000);

  alert_bell (1);
  delay (50);
  alert_bell (0);
  led_test (0);

  fault_state = 0;
  fet_drv_state (0);
  ov_led_set (0);
  oc_led_set (0);

  // reload old V & C limits
//#define DEFAULT_OV_LIMIT  (13.5)
//#define DEFAULT_OC_LIMIT  (2.0)
// static float max_voltage_limit = 20.0;
// static float max_current_limit = 10.0;  // normal value of 4A

  voltage_limit = getVoltageSetting(); // from FRAM
  if (voltage_limit > max_voltage_limit) { // 20.0
      Serial.printf("Out of range Volt limit: %3.2fV, Used default value\n", voltage_limit);
      voltage_limit = DEFAULT_OV_LIMIT;
  }
  current_limit = getCurrentSetting();
  if (current_limit > max_current_limit) {  // 10.0
      Serial.printf("Out of range current limit: %3.2fA, Used default value\n", current_limit);
      current_limit = DEFAULT_OC_LIMIT;    
  }
  
  Serial.printf("Using saved Voltage limit: %3.2fV\n", voltage_limit);
  Serial.printf("Using saved Current limit: %3.2fA\n", current_limit );

  voltage_limit_set (voltage_limit);
  current_limit_set (current_limit);

  Serial.printf("Setup done, jump to Loop\n");

  // enable fault interrupt
  ina228_alr_int_flag=0;
  pinMode(INA228_ALR, INPUT_PULLUP);
  attachInterrupt(INA228_ALR, isr, FALLING);
}

void
loop ()
{
  static int display_update_time = 0;
  static int pot_update_time = 0;
  static int fault_update_time = 0;
  static int settings_update_time = 0;
  static bool op_sw_state = 0;
  int alert_status = 0;

  if ((millis () - settings_update_time) > 1000) {
    settings_update_time = millis ();

    if (dirty_ov_setting) {
      voltage_limit_set (voltage_limit);
       saveVoltageSetting(voltage_limit);
       dirty_ov_setting = 0;
       Serial.printf ("%s(%d) Voltage Limit Up date: voltage: %03.3fV, current: %03.3fA\n", __func__, __LINE__,
                   voltage_limit, current_limit);
    }
    if (dirty_oc_setting) {
       saveCurrentSetting(current_limit);
       current_limit_set (current_limit);
       dirty_oc_setting = 0;
       Serial.printf ("%s(%d) Current Limit Up date: voltage: %03.3fV, current: %03.3fA\n", __func__, __LINE__,
                   voltage_limit, current_limit);
    }
  }

  if ((millis () - display_update_time) > 100) {
    display_update_time = millis ();
    display_update ();
  }

  // update fault pot setting
  if ((millis () - pot_update_time) > 200) {
    pot_update_time = millis ();

    // Check voltage setting change
    float voltage_diff=0.0;
    new_OV_Position = OV_Enc.read();
    if (new_OV_Position != old_OV_Position) {
      Position_Diff = new_OV_Position - old_OV_Position;
      voltage_diff = ((float)Position_Diff) * -0.05;
      voltage_limit = voltage_limit - voltage_diff;
      Serial.printf ("%s(%d) OV %d %d %d\n", __func__, __LINE__,new_OV_Position,old_OV_Position ,Position_Diff);
      old_OV_Position = new_OV_Position;
//      saveVoltageSetting(voltage_limit);
//      voltage_limit_set (voltage_limit);  // Not sure this is required
      dirty_ov_setting = 1;
    }

    // Check Current setting change
    float current_diff=0.0;
    new_OC_Position = OC_Enc.read();
    if (new_OC_Position != old_OC_Position) {
      Position_Diff = new_OC_Position - old_OC_Position;
      current_diff = ((float)Position_Diff) * -0.05;
      current_limit = current_limit - current_diff;
      Serial.printf ("%s(%d) OC %d %d %d\n", __func__, __LINE__,new_OC_Position,old_OC_Position ,Position_Diff);
      old_OC_Position = new_OC_Position;
//      saveCurrentSetting(current_limit);
//      current_limit_set (current_limit); // Not sure this is required
      dirty_oc_setting = 1;
    }
  }

  button.poll ();             // Check output button state
  op_sw_state = button.toggle ();

  if (((millis () - fault_update_time) > 10) || (ina228_alr_int_flag)) {
    fault_update_time = millis ();
    alert_status = ina228_reg_read(0x0B);
    // check OC & OV faults
    if (ina228_alr_int_flag) {
       ina228_alr_int_flag = 0;
//      Serial.printf ("%s(%d) ina228_alr_int_flag set 0x%04X\n", __func__, __LINE__,alert_status);
    }

    if (alert_status & (OV_FAULT_BIT | OC_FAULT_BIT)) {
      read_voltage_current (&fault_voltage, &fault_current);  // capture current readings
      fault_state = 1;
      ov_led_set (alert_status & OV_FAULT_BIT);
      oc_led_set (alert_status & OC_FAULT_BIT);
      fet_drv_state (0);
      button.setToggleState (0);        // reset button toggle state
      alert_bell (1);
      if (alert_status & OV_FAULT_BIT) {
#if 0
         Serial.printf("%s(%d) Voltage Fault: %03.3fV, limit: %03.3fV, status reg: 0x%04X\n", 
                                __func__, __LINE__, fault_voltage, voltage_limit, alert_status);
#endif   
      } 
      if (alert_status & OC_FAULT_BIT) {
         Serial.printf("%s(%d) Current Fault: %03.3fA, limit: %03.3fA, status reg: 0x%04X\n", 
                                __func__, __LINE__, fault_current, current_limit, alert_status);
     } 
    }
    else if (fault_state == 0) {
      ov_led_set (0);
      oc_led_set (0);
    }

    if ((digitalRead (OV_ENC_SW) == 0) || (digitalRead (OC_ENC_SW) == 0)) { //AL_RST_SW) == 0) {
      fault_state = 0;
      alert_bell (0);
      fet_drv_state (0);
      button.setToggleState (0);        // reset button toggle state
    }

    if (op_sw_state) {
      fet_drv_state (1);
    }
    else {
      fet_drv_state (0);
    }
  }

  yield ();
}

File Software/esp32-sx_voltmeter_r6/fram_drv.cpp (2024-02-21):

#include <Wire.h>
//#include <Adafruit_GFX.h>
#include <Arduino.h>

// indent -gnu -br -cli2 -lp -nut -l100 fram_drv.cpp
// https://nightshade.net/knowledge-base/electronics-tutorials/arduino/intro-to-arduino-i2c-serial-communication-links/
// https://cdn-shop.adafruit.com/product-files/1895/MB85RC256V-DS501-00017-3v0-E.pdf
// https://github.com/sosandroid/FRAM_MB85RC_I2C/blob/master/FRAM_MB85RC_I2C.cpp#L673

int fram__get_dev_id (void);
void i2c_scan (void);
int fram_read_bytes (uint16_t fram_adr, uint8_t * ptr, int len);
int fram_write_bytes (uint16_t fram_adr, uint8_t * ptr, int len);

void
i2c_scan (void)
{
  uint8_t error;

  Serial.begin (115200);
  Serial.printf ("%s(%d)\n", __func__, __LINE__);

  /// Fram test  
  Wire.begin ();

  Serial.printf ("I2C Scan\n");

  uint8_t address;
  int nDevices;
  Serial.printf ("Scanning...\n");
  nDevices = 0;
  for (address = 1; address < 127; address++) {
    Wire.beginTransmission (address);
    error = Wire.endTransmission ();
    if (error == 0) {
      Serial.print ("I2C device found at address 0x");
      if (address < 16) {
        Serial.print ("0");
      }
      Serial.println (address, HEX);
      nDevices++;
    }
    else if (error == 4) {
      Serial.print ("Unknow error at address 0x");
      if (address < 16) {
        Serial.print ("0");
      }
      Serial.println (address, HEX);
    }
  }
  if (nDevices == 0) {
    Serial.println ("No I2C devices found\n");
  }
  else {
    Serial.println ("done\n");
  }
}

#define FRAME_MASTER_CODE (0xF8)
#define FRAME_I2C_ADR (0x50)
int
fram_get_dev_id (void)
{
  uint8_t error;
  uint8_t rx[4];
  int manufacture_id = 0;
  int product_id = 0;

  Serial.printf ("%s(%d)\n", __func__, __LINE__);

  Wire.begin ();

  Wire.beginTransmission (0xF8 >> 1);   // Should use MASTER_CODE
  Wire.write (FRAME_I2C_ADR << 1);      // Write the register address that we want to target
  error = Wire.endTransmission (0);

  Wire.requestFrom (FRAME_MASTER_CODE >> 1, 3);       // Read 3 byte from slave address

  for (int i = 0; i < 4; i++) {
    rx[i] = Wire.read ();       // Read bytes from registers
  }
  Wire.endTransmission ();

  manufacture_id = rx[1] >> 4;
  product_id = ((rx[1] & 0x0f) << 8) | rx[2];
  Serial.printf ("Fram ID Bytes: 0x%02X, 0x%02X, 0x%02X\n", rx[0], rx[1], rx[2]);
  Serial.printf ("manufacture_id: 0x%04X, product_id: 0x%02X\n", manufacture_id, product_id);

  Serial.printf ("%s(%d)\n", __func__, __LINE__);
  if ((manufacture_id == 0x0A) && (product_id == 0x358)) {
    return 0;
  }
  else {
    return -1;
  }
}

int
fram_read_bytes (uint16_t fram_adr, uint8_t * ptr, int len)
{
  unsigned long start_time = micros();
  unsigned long stop_time;

  Wire.begin ();
  //Wire.setClock(800000);

  Wire.beginTransmission (FRAME_I2C_ADR);       // Begin communication with slave address 85 (0x55) 
  Wire.write (fram_adr >> 8);
  Wire.write (fram_adr & 0xFF); // Write the value that we want in register 12 
  Wire.endTransmission (0);     // Send the restart condition

  Wire.requestFrom (FRAME_I2C_ADR, len);        //
  for (int i = 0; i < len; i++) {
    ptr[i] = Wire.read ();      // Read bytes from registers
  }
  stop_time = micros() - start_time;

  Serial.printf ("%s(%d) Adr 0x%04X: 0x%02X 0x%02X 0x%02X 0x%02X, %ld us\n", __func__, __LINE__, fram_adr,
                 ptr[0], ptr[1], ptr[2], ptr[3], stop_time);
  return 0;
}

int
fram_write_bytes (uint16_t fram_adr, uint8_t * ptr, int len)
{
//  Serial.printf ("%s(%d) Adr 0x%04X: 0x%02X 0x%02X 0x%02X 0x%02X\n", __func__, __LINE__, fram_adr,
//                 ptr[0], ptr[1], ptr[2], ptr[3]);
  unsigned long start_time = micros();
  unsigned long stop_time;

  Wire.begin ();
  //Wire.setClock(800000);

  Wire.beginTransmission (FRAME_I2C_ADR);       // Begin communication with slave address 85 (0x55) 
  Wire.write (fram_adr >> 8);
  Wire.write (fram_adr & 0xFF); // Write the value that we want in register 12 
  for (int i = 0; i < len; i++) {
    Wire.write (ptr[i]);        // Read bytes from registers
  }
  Wire.endTransmission ();      // Send the stop condition and end the transaction
  ptr[0]++;
  stop_time = micros() - start_time;
  Serial.printf ("%s(%d) Adr 0x%04X: 0x%02X 0x%02X 0x%02X 0x%02X, %ld us\n", __func__, __LINE__, fram_adr,
                 ptr[0], ptr[1], ptr[2], ptr[3], stop_time);

  uint8_t rd_back[10];
  fram_read_bytes (fram_adr, rd_back, len);
  if (ptr[0] != rd_back[0]) {
      Serial.printf ("%s(%d) ReadBack err 0x%04X: 0x%02X 0x%02X\n", __func__, __LINE__, fram_adr, ptr[0], rd_back[0]);
  }
  return 0;
}

#if 0
void
reg_dump (int reg)
{
  int reg_value = 0x73;

  reg_value = ina228.reg_read (reg);    // jok
  Serial.printf ("INA228 reg[%02X] 0x%04X\n", reg, reg_value);
}
#endif

#define INA228_I2C_ADR (0x40)
int
ina228_reg_read(int reg)
{
  uint8_t data[4];
  uint16_t reg_value=0;

  Wire.begin ();
//  Wire.setClock(100000);

  Wire.beginTransmission (INA228_I2C_ADR);  // Begin communication with slave address (0x40) 
  Wire.write (reg);
  Wire.endTransmission (0);     // Send the restart condition

  Wire.requestFrom (INA228_I2C_ADR, 3);        //
  data[0] = Wire.read ();      // Read bytes from registers
  data[1] = Wire.read ();      // Read bytes from registers

  reg_value = (data[0]<<8) | data[1];
//  Serial.printf ("INA228 reg[%02X] 0x%04X\n", reg, reg_value);
  return reg_value;
}

int
ina228_reg_write(int reg, uint16_t reg_value)
{
  Serial.printf ("INA228 reg[%02X] 0x%04X\n", reg, reg_value);

  Wire.begin ();

  Wire.beginTransmission (INA228_I2C_ADR);       // Begin communication with slave address 85 (0x55) 
  Wire.write (reg); // send reg adr
  Wire.write (reg_value>>8); // Write the value that we want in register 12 
  Wire.write (reg_value & 0xFF); // Write the value that we want in register 12 
  Wire.endTransmission ();      // Send the stop condition and end the transaction

  return 0;
}

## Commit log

2024-02-16 major update
    [eFuse_voltmeter_r6-B_Cu.gbl, eFuse_voltmeter_r6-B_Mask.gbs, eFuse_voltmeter_r6-B_Paste.gbp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]
2024-02-22 swap in a file
    [esp32-sx_voltmeter_r6.ino]
